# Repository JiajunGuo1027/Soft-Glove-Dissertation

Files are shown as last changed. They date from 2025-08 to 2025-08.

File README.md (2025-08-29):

# Design and Closed-Loop Control of a Cable-Driven Soft Robotic Glove for Post-Stroke Rehabilitation
This project aims to construct a soft glove-based passive rehabilitation training system to serve the finger rehabilitation process of patients with upper limb motor dysfunction after stroke.

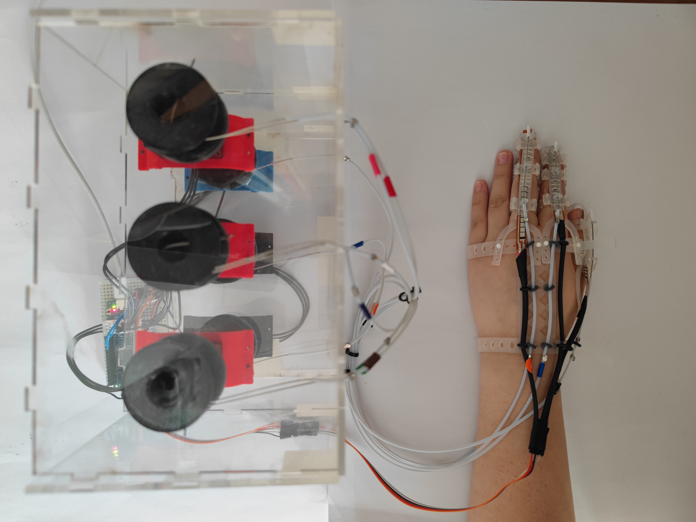
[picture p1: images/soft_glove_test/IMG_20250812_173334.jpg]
Description
 

## Overview
This repository contains the complete implementation of a **cable-driven soft exoskeleton glove** developed for passive rehabilitation of post-stroke patients.  
The system enables repeatable flexion–extension cycles of the thumb, index, and middle fingers using cable-driven actuation with integrated sensing and closed-loop control.  

Watch the video (https://youtu.be/nIMEAH1Ccxk)

**Key Features:**
- Modular glove design with silicone structures and 3D-printed connectors.  
- Six Dynamixel XL330-M288-T motors for tendon-driven flexion/extension.  
- Flex sensor–based multimodal modeling framework (L–θ, R–L, R–θ mappings).  
- Closed-loop controller with sensor-based angle estimation (camera-free).  
- Complete experimental pipeline including tensile testing, data acquisition, modeling, and evaluation.  

---

## Repository Structure
```
Soft_glove/
├─ code/ # Source code
│ ├─ script/anagle_detect/ # Video-based joint angle extraction
│ │ ├─ angle_detect_index.py
│ │ ├─ angle_detect_middle.py
│ │ └─ angle_detect_thumb.py
│ ├─ script/model/ # Modeling scripts (L–θ, R–L, R–θ)
│ │ ├─ model_L_theta.py
│ │ ├─ model_R_L.py
│ │ ├─ model_R_theta_compose_active.py
│ │ └─ model_R_theta_direct.py
│ └─ OpenRB150/ # Embedded control firmware
│   ├─ flex_extend_sensor_test/
│   │ └─ flex_extend_sensor_test.ino
│   └─ close_loop_control/
│     └─ close_loop_control.ino
│
├─ data/ # Raw experimental data
│ ├─ raw/ # Serial data logs
│ └─ video/ # Video recordings for joint angle extraction
│
├─ output/ # Processed results
│ ├─ index_angles/ # Aligned data for index finger
│ │ └─ aligned_data_index.csv
│ ├─ middle_angles/ # Aligned data for middle finger
│ │ └─ aligned_data_middle.csv
│ ├─ thumb_angles/ # Aligned data for thumb
│ │ └─ aligned_data_thumb.csv
│ └─ control_results/ # Closed-loop control logs and evaluation plots
│
├─ models/ # Trained models (JSON/CSV/plots)
│ ├─ index/
│ │ ├─ L_theta/ L_theta_model.json, L_theta_summary_index.csv
│ │ ├─ R_L/ R_L_model.json, R_L_summary_index.csv
│ │ ├─ R_theta_direct/ R_theta_direct_model_index.json
│ │ └─ R_theta_compose_active/ (composed model + active session data)
│ ├─ middle/ # Similar structure, mainly R–L models
│ └─ thumb/ # Same as index
│
├─ images/ # Figures and plots for reports/papers
│ ├─ article/ # Final paper figures
│ ├─ design_sketch/ # Glove design illustrations
│ └─ soft_glove_test/ # Project photos
│
├─ SOLIDWORKS 2024/ # CAD models
│ ├─ Glove_final_design/ # Final glove design
│ ├─ 3D_Print_connector/ # Connector models
│ └─ other .SLDPRT files # Palm and finger modules
│
├─ tensile/ # Tensile testing data and results
└─ requirements.txt # Python dependencies
```

---

## Core Files

- **Final aligned data:**  
  - `output/index_angles/aligned_data_index.csv`  
  - `output/middle_angles/aligned_data_middle.csv`  
  - `output/thumb_angles/aligned_data_thumb.csv`  

- **Key trained models:**  
  - `models/index/L_theta/L_theta_model.json`  
  - `models/index/R_L/R_L_model.json`  
  - `models/index/R_theta_compose_active/R_theta_composed_model_ACTIVE.json`  

- **Control firmware:**  
  - `code/OpenRB150/close_loop_control/close_loop_control.ino`

---

## How to Use

1. **Preprocess video & sensor data**  
   Run scripts in `code/script/anagle_detect/` to extract joint angles from marker-based video.  

2. **Train models (L–θ, R–L, R–θ)**  
   Use the scripts in `code/script/model/` to fit regression models.  

3. **Upload firmware**  
   Flash `closeloop_control.ino` to the OpenRB-150 board.  

4. **Run closed-loop experiments**  
   Collect results in `output/control_results/` and visualize using provided Python scripts.  

---

## Notes
- The repository also contains **debug files, early tests, and discarded attempts** for completeness and reproducibility.  
- Final analysis and plots for the dissertation were generated from the files highlighted in **Core Files**.  

---

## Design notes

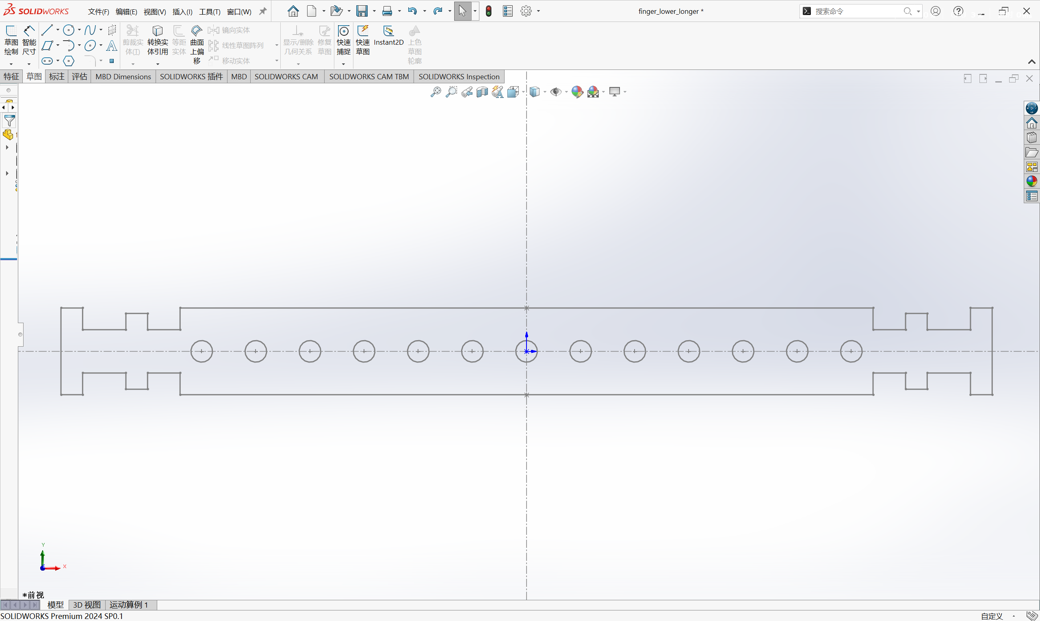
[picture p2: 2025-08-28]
images/design_sketch/finger_lower_longer.png

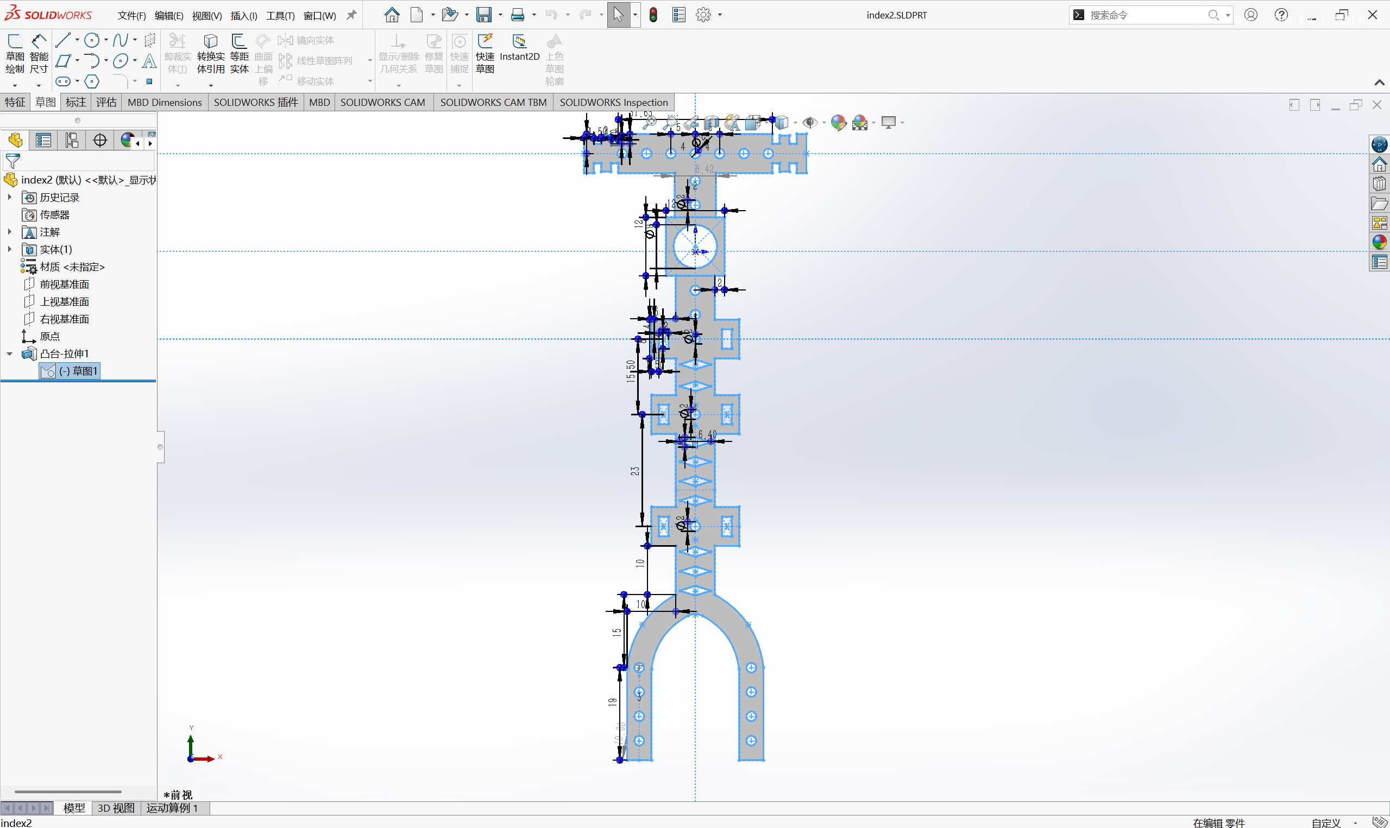
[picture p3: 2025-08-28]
images/design_sketch/index_upper_sketch.png

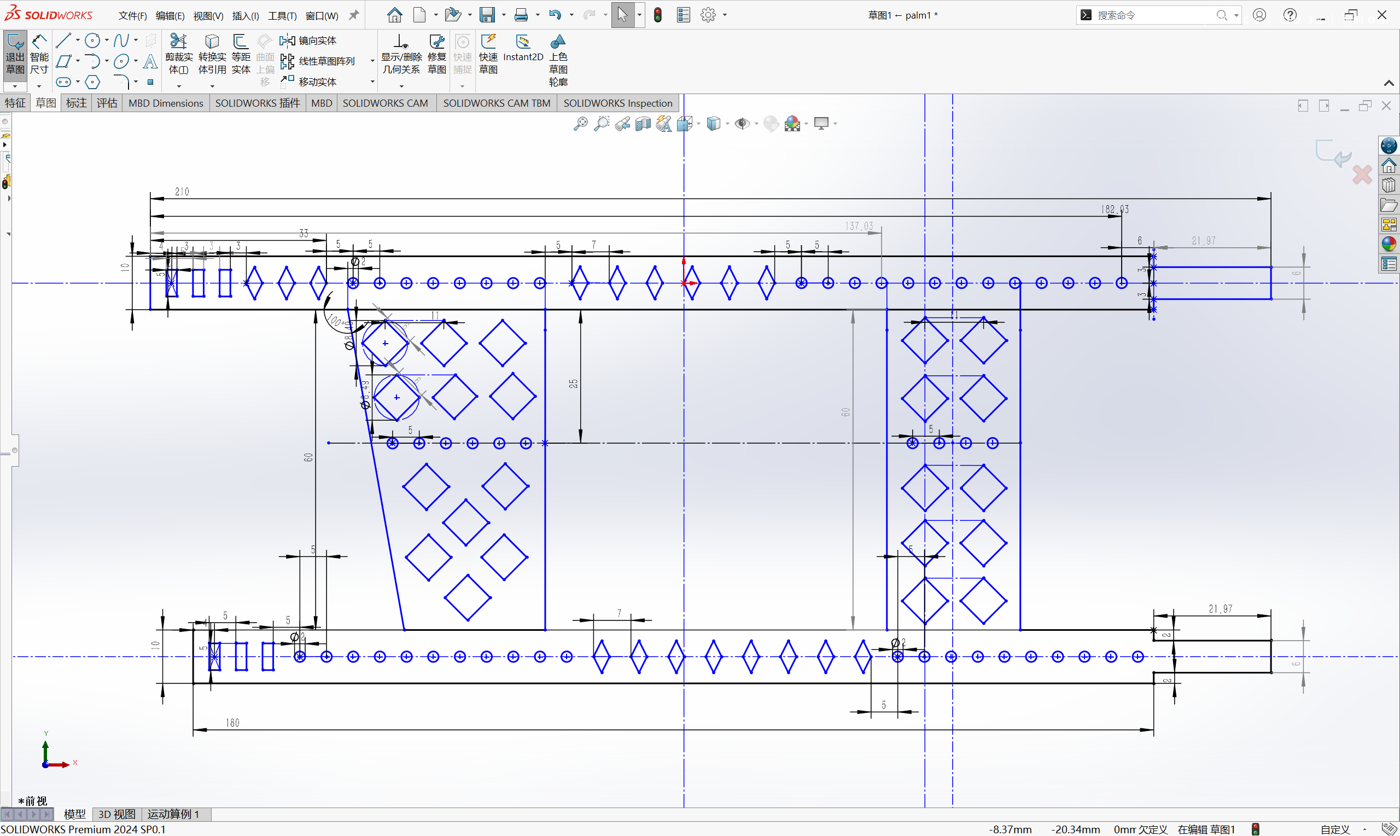
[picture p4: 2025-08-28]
images/design_sketch/palm_sketch.png

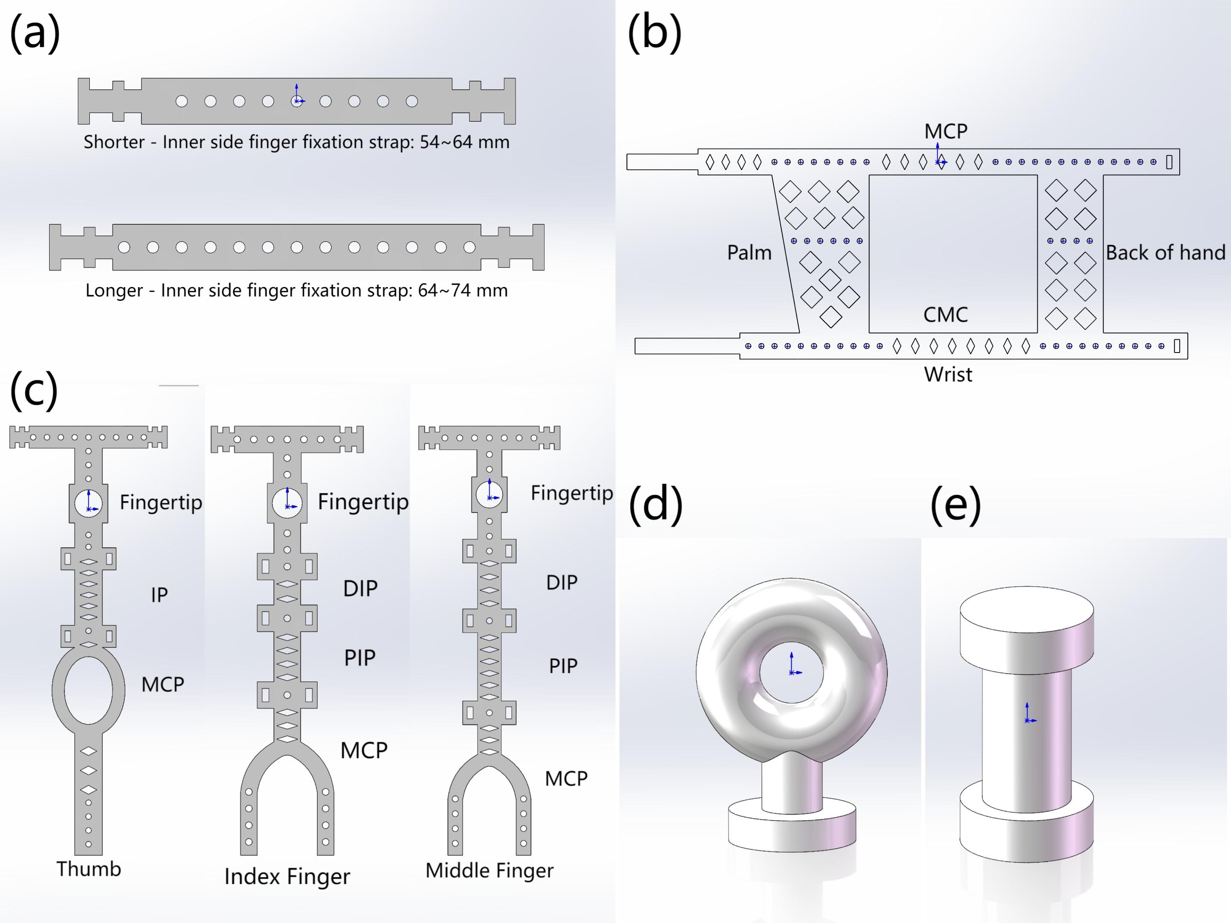
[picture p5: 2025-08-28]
images/article/design.jpg

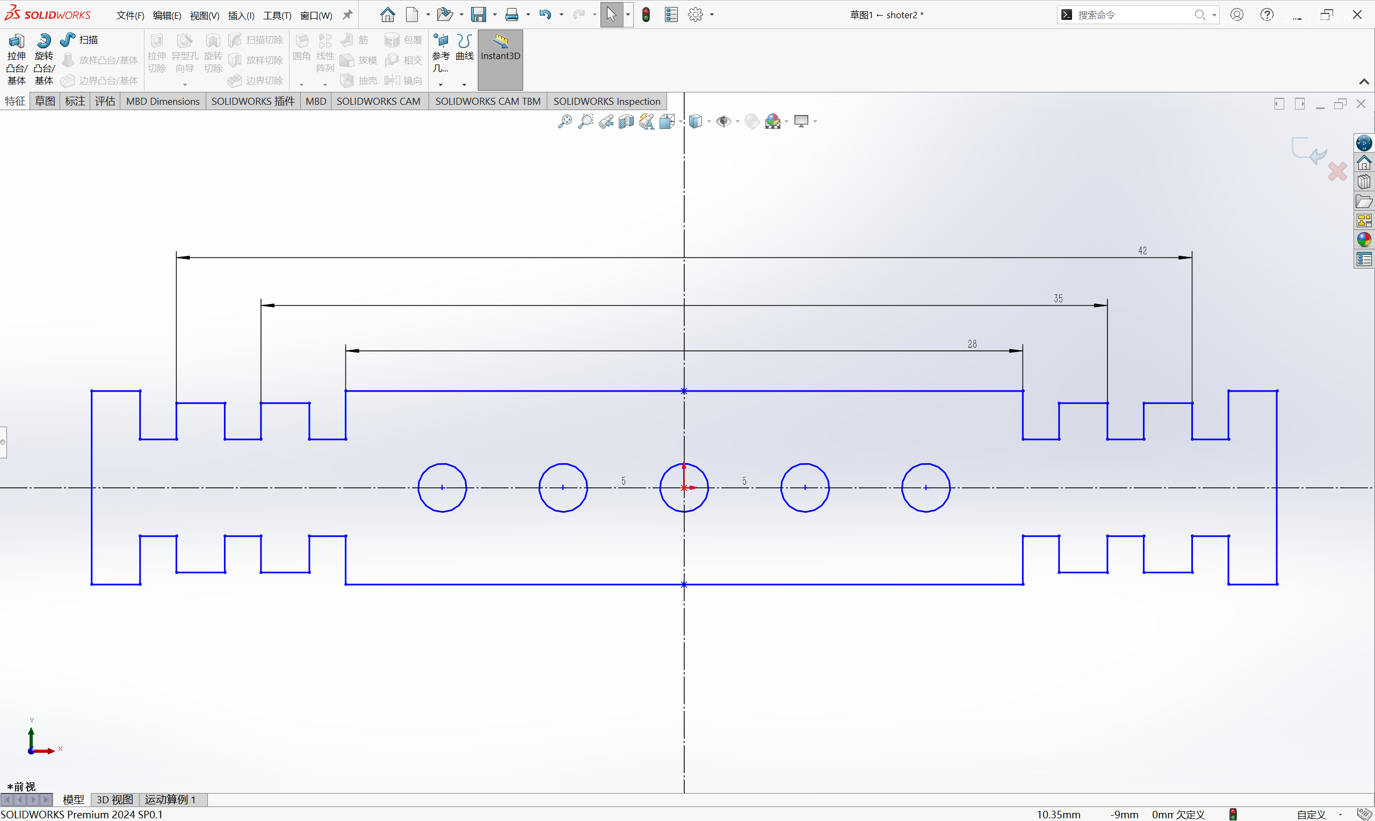
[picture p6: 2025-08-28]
images/design_sketch/shoter2.png

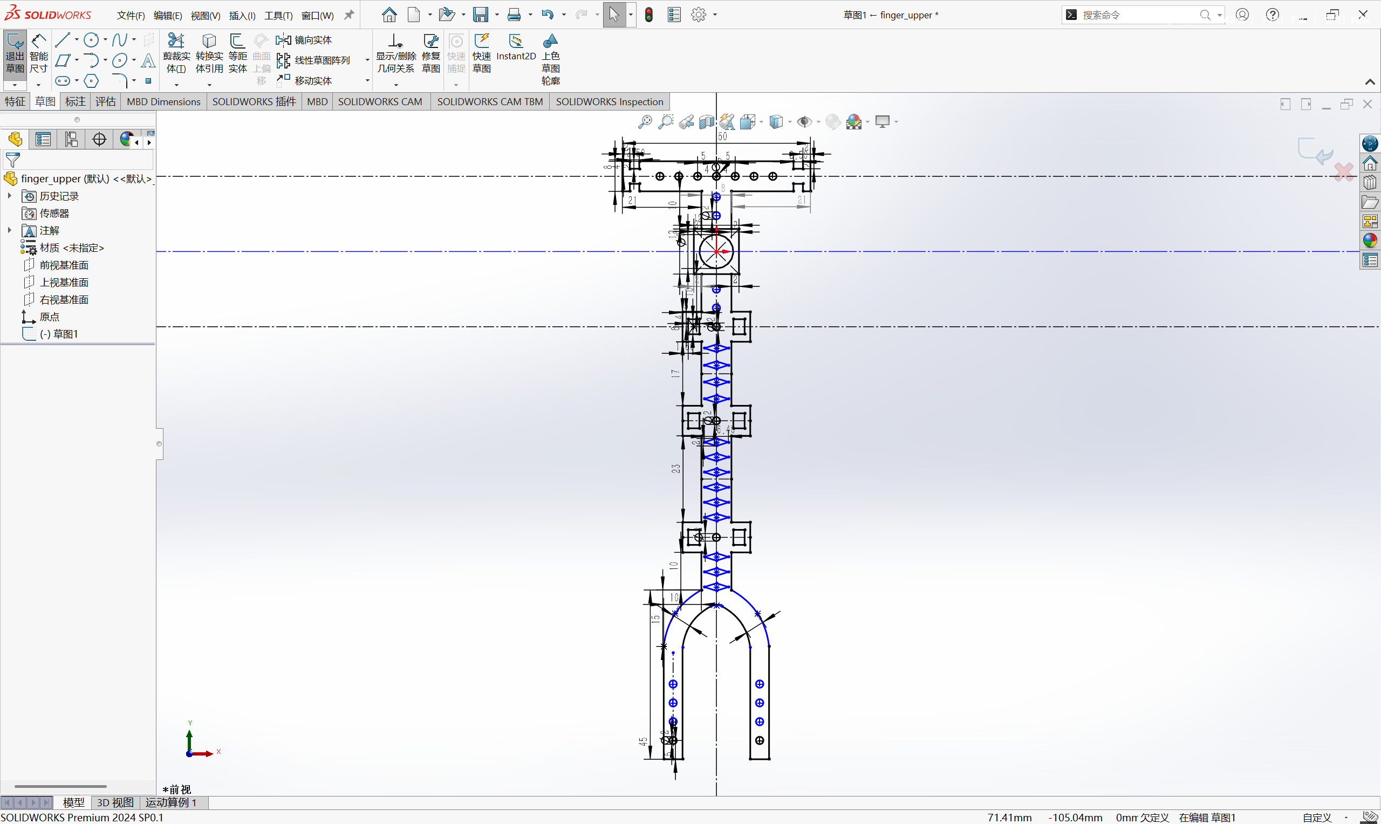
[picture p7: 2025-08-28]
images/design_sketch/finger_upper_sketch.png

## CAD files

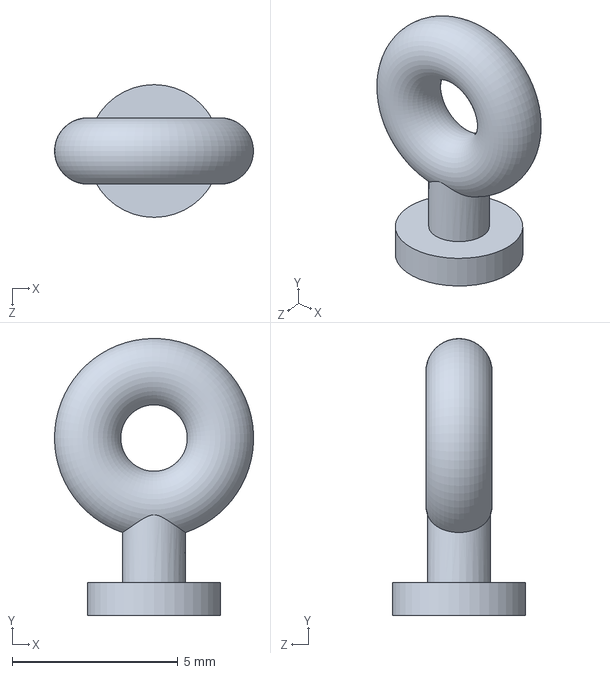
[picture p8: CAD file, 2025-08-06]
SOLIDWORKS 2024/3D_Print/30_cable2mm.SLDPRT
6.00 x 8.34 x 4.00 mm

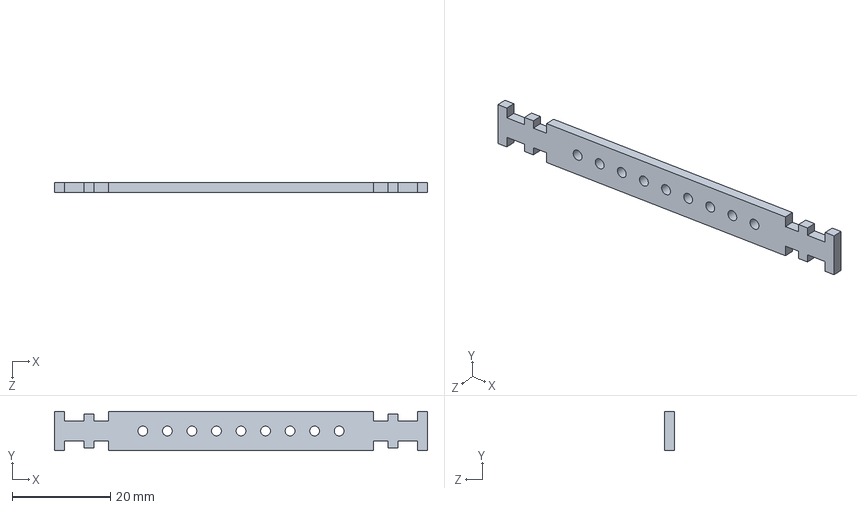
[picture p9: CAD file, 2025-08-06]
SOLIDWORKS 2024/finger_lower_shoter_3D.SLDPRT
76.0 x 8.00 x 2.00 mm

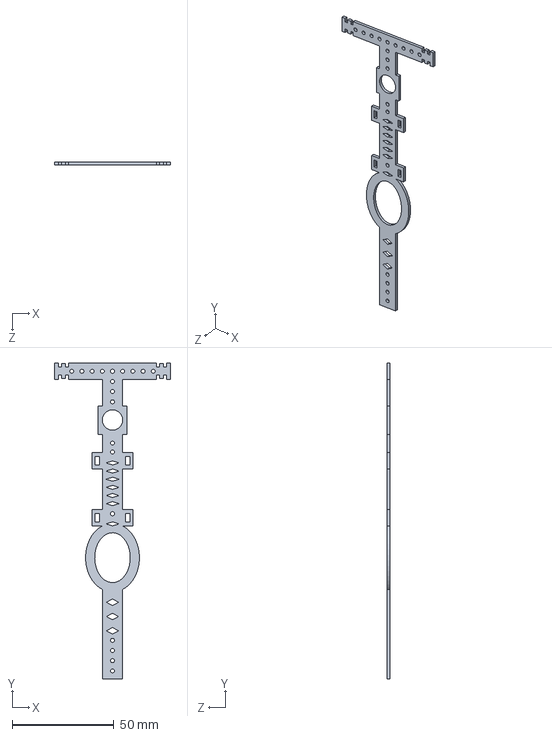
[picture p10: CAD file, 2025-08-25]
SOLIDWORKS 2024/Glove_final_design/thumb3.SLDPRT
57.0 x 155.1 x 1.50 mm

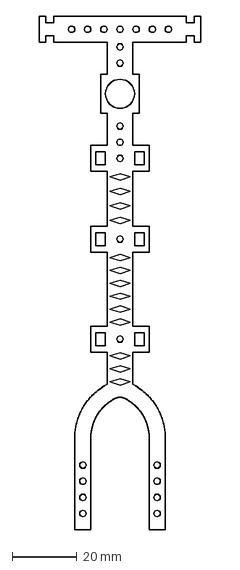
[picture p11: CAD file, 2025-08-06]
SOLIDWORKS 2024/LaserCut1/finger_upper_3D.DXF
50.0 x 159.0 mm

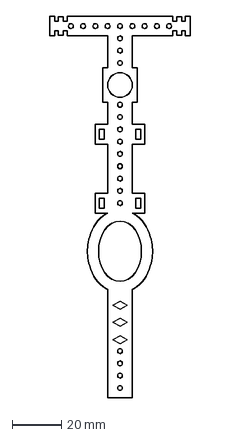
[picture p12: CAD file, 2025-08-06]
SOLIDWORKS 2024/LaserCut2/1_thumb2.DXF
57.0 x 155.1 mm

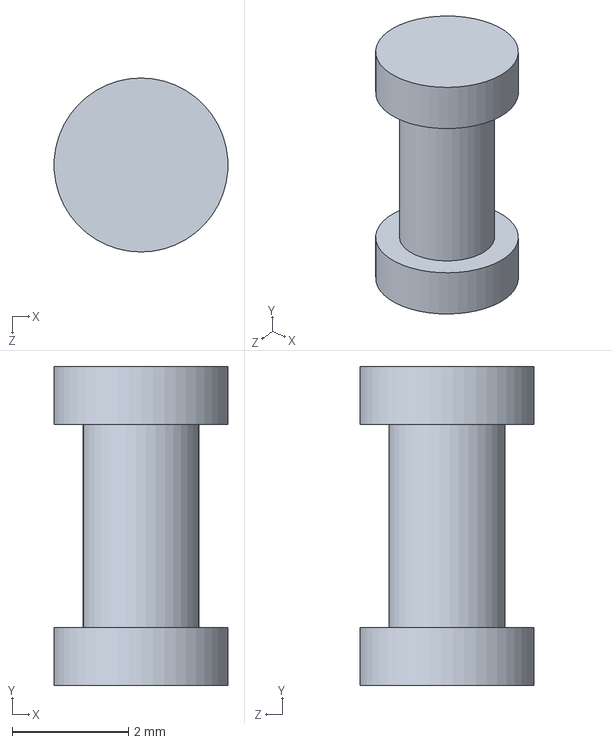
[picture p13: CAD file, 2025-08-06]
SOLIDWORKS 2024/3D_Print/10_connector1.SLDPRT
2.99 x 5.50 x 3.00 mm

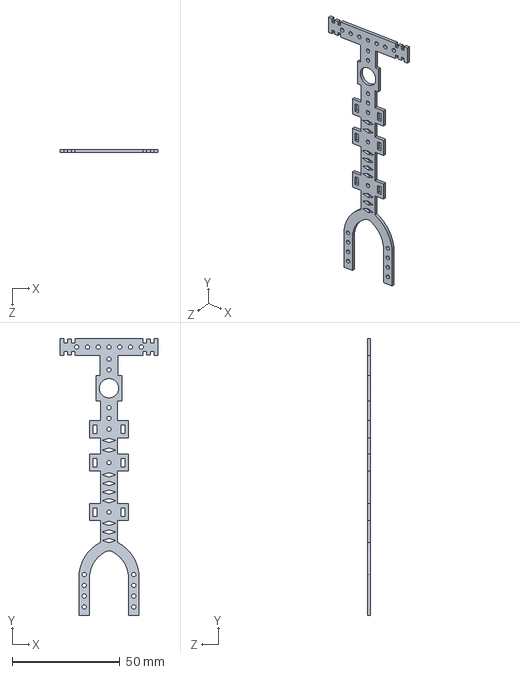
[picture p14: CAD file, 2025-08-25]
SOLIDWORKS 2024/Glove_final_design/index2.SLDPRT
45.6 x 128.6 x 1.50 mm

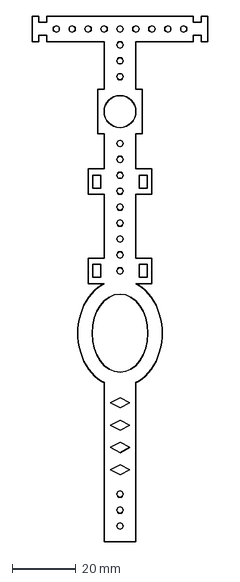
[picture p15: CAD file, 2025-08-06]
SOLIDWORKS 2024/LaserCut1/thumb_upper_3D.DXF
55.0 x 165.1 mm

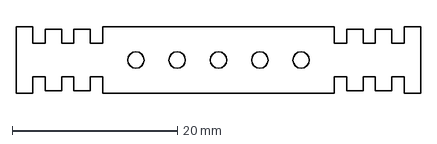
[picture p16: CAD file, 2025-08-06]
SOLIDWORKS 2024/LaserCut2/3_shoter2.DXF
49.0 x 8.00 mm

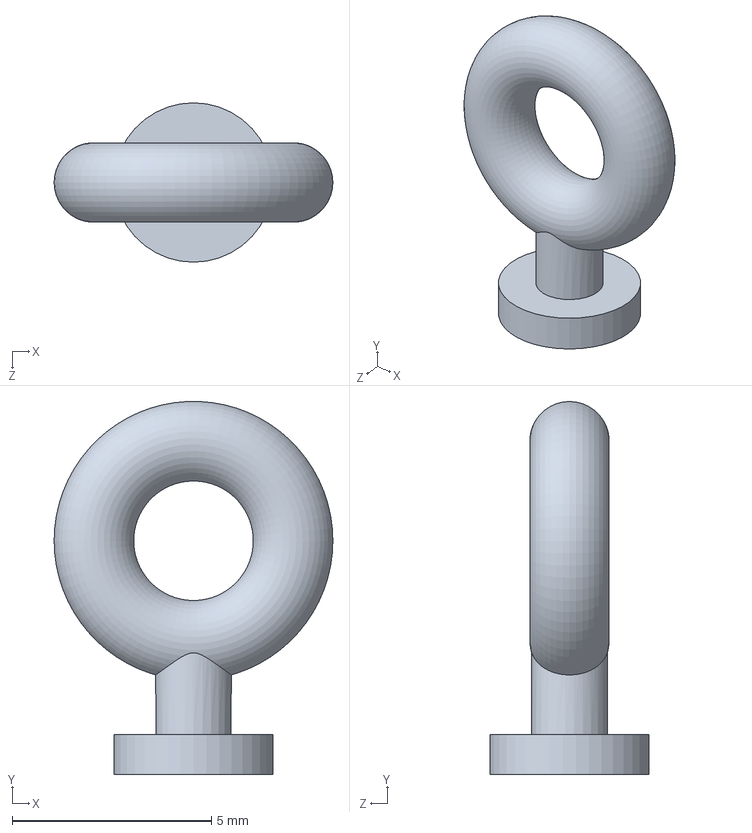
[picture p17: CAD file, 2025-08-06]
SOLIDWORKS 2024/3D_Print/30_cable3mm.SLDPRT
7.00 x 9.37 x 4.00 mm

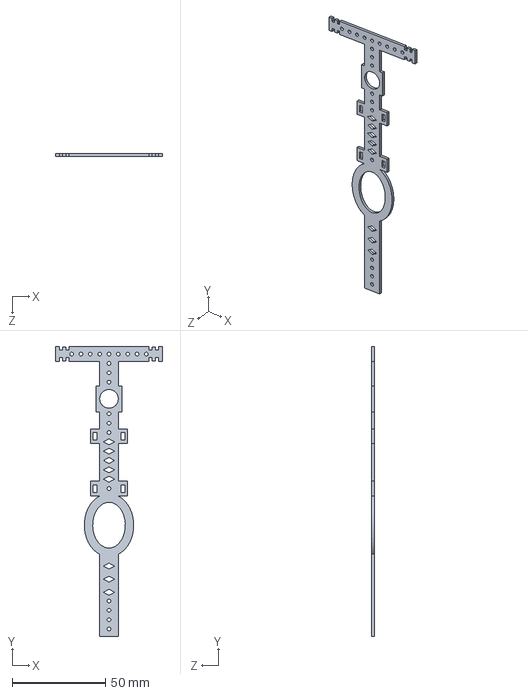
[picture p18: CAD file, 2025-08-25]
SOLIDWORKS 2024/Glove_final_design/thumb2.SLDPRT
57.0 x 155.1 x 1.50 mm

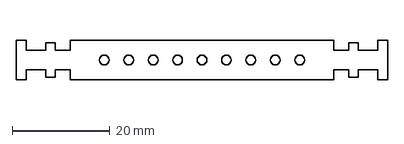
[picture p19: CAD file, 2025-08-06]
SOLIDWORKS 2024/LaserCut1/finger_lower_shoter_3D.DXF
76.0 x 8.00 mm

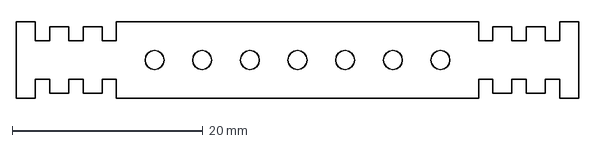
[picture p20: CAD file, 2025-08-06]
SOLIDWORKS 2024/LaserCut2/3_longer2.DXF
59.0 x 8.00 mm

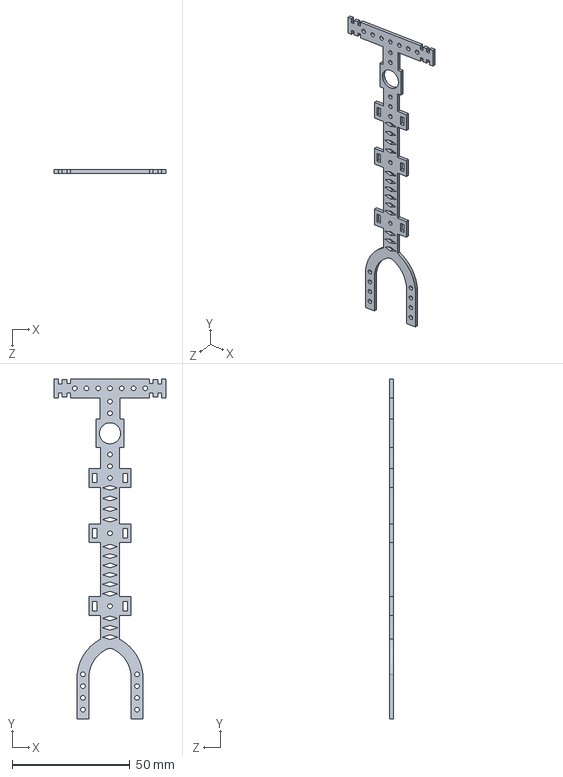
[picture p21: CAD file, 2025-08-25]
SOLIDWORKS 2024/Glove_final_design/middle2.SLDPRT
47.6 x 144.6 x 1.50 mm

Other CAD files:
SOLIDWORKS 2024/finger_lower_longer.SLDPRT
SOLIDWORKS 2024/finger_under1.SLDPRT
SOLIDWORKS 2024/finger_lower_2D.SLDPRT
SOLIDWORKS 2024/LaserCut1/finger_lower_longer _3D.DXF
SOLIDWORKS 2024/Glove_final_design/longer2.SLDPRT
SOLIDWORKS 2024/Glove_final_design/palm2.SLDPRT
SOLIDWORKS 2024/Glove_final_design/shoter2.SLDPRT
SOLIDWORKS 2024/LaserCut1/palm1_3D.DXF
SOLIDWORKS 2024/LaserCut2/1_index2.DXF
SOLIDWORKS 2024/LaserCut2/1_middle2.DXF
SOLIDWORKS 2024/LaserCut2/1_palm2.DXF
SOLIDWORKS 2024/finger_lower_longer _3D.SLDPRT
SOLIDWORKS 2024/finger_lower_shoter.SLDPRT
SOLIDWORKS 2024/finger_upper.SLDPRT
SOLIDWORKS 2024/finger_upper_3D.SLDPRT
SOLIDWORKS 2024/palm1.SLDPRT
SOLIDWORKS 2024/palm1_3D.SLDPRT
SOLIDWORKS 2024/thumb1.SLDPRT
SOLIDWORKS 2024/thumb_upper.SLDPRT
SOLIDWORKS 2024/thumb_upper_3D.SLDPRT
SOLIDWORKS 2024/train.SLDPRT

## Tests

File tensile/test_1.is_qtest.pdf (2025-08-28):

Sample text inputs: Sample text input | thumb0

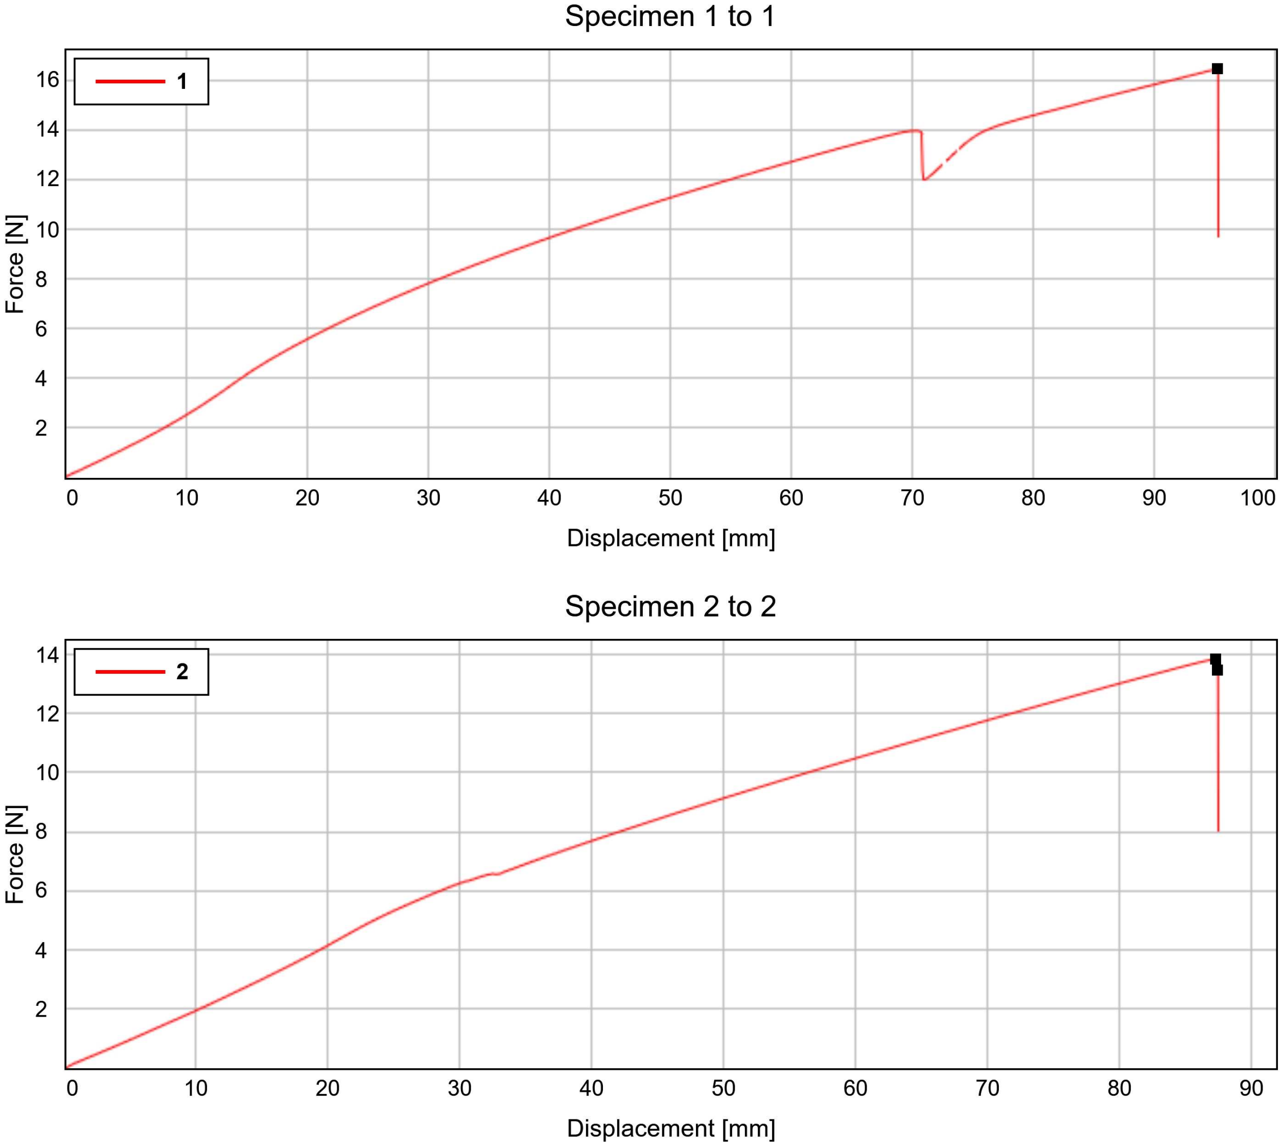
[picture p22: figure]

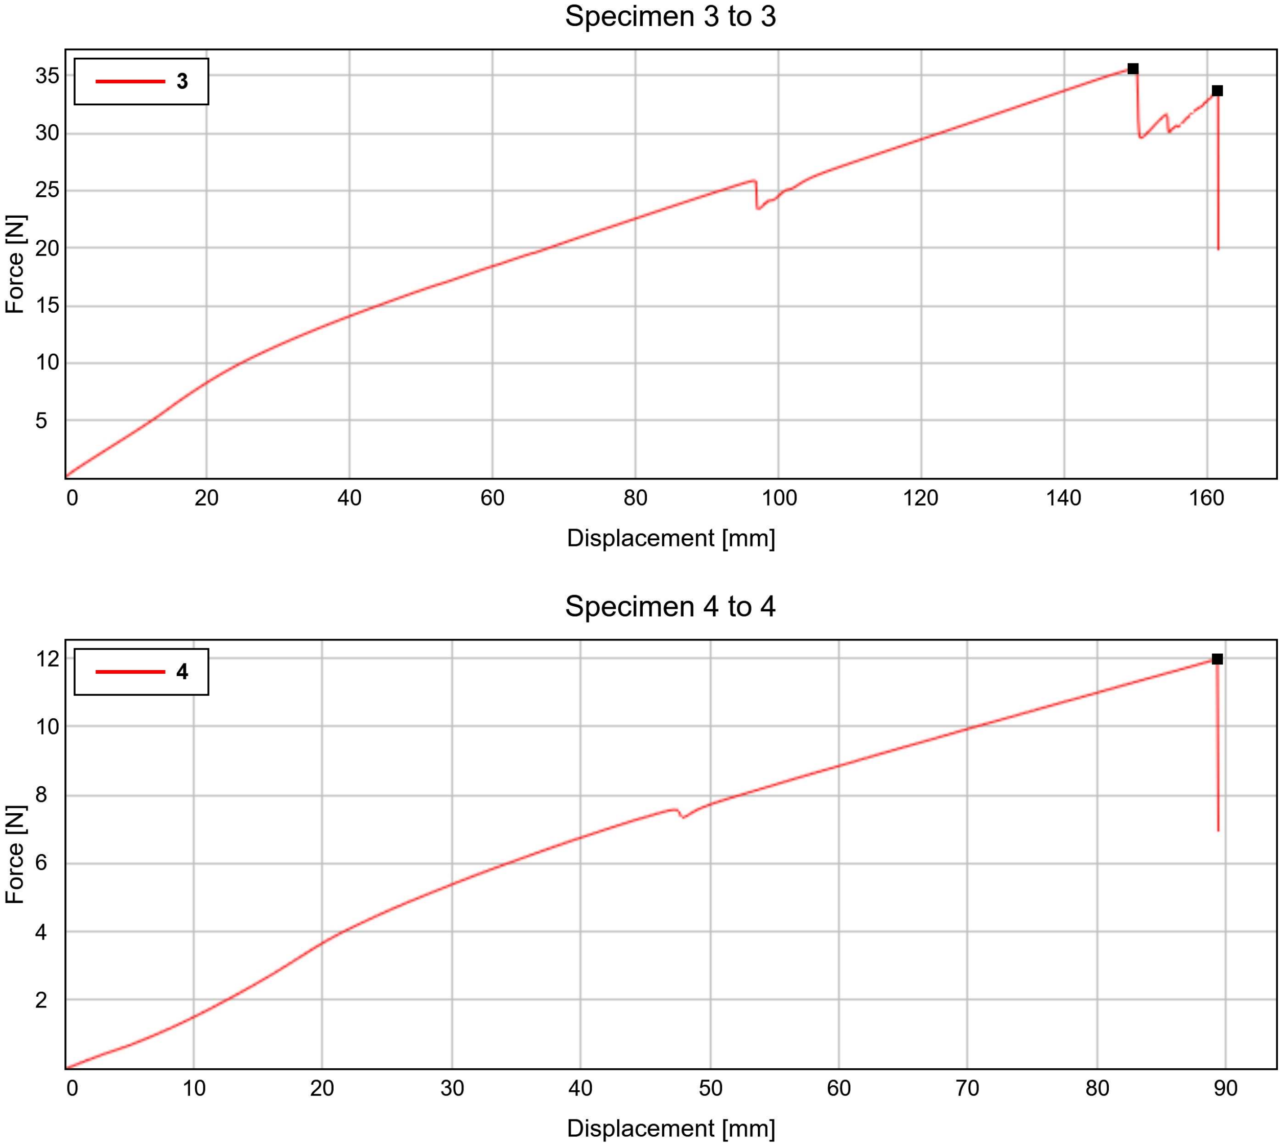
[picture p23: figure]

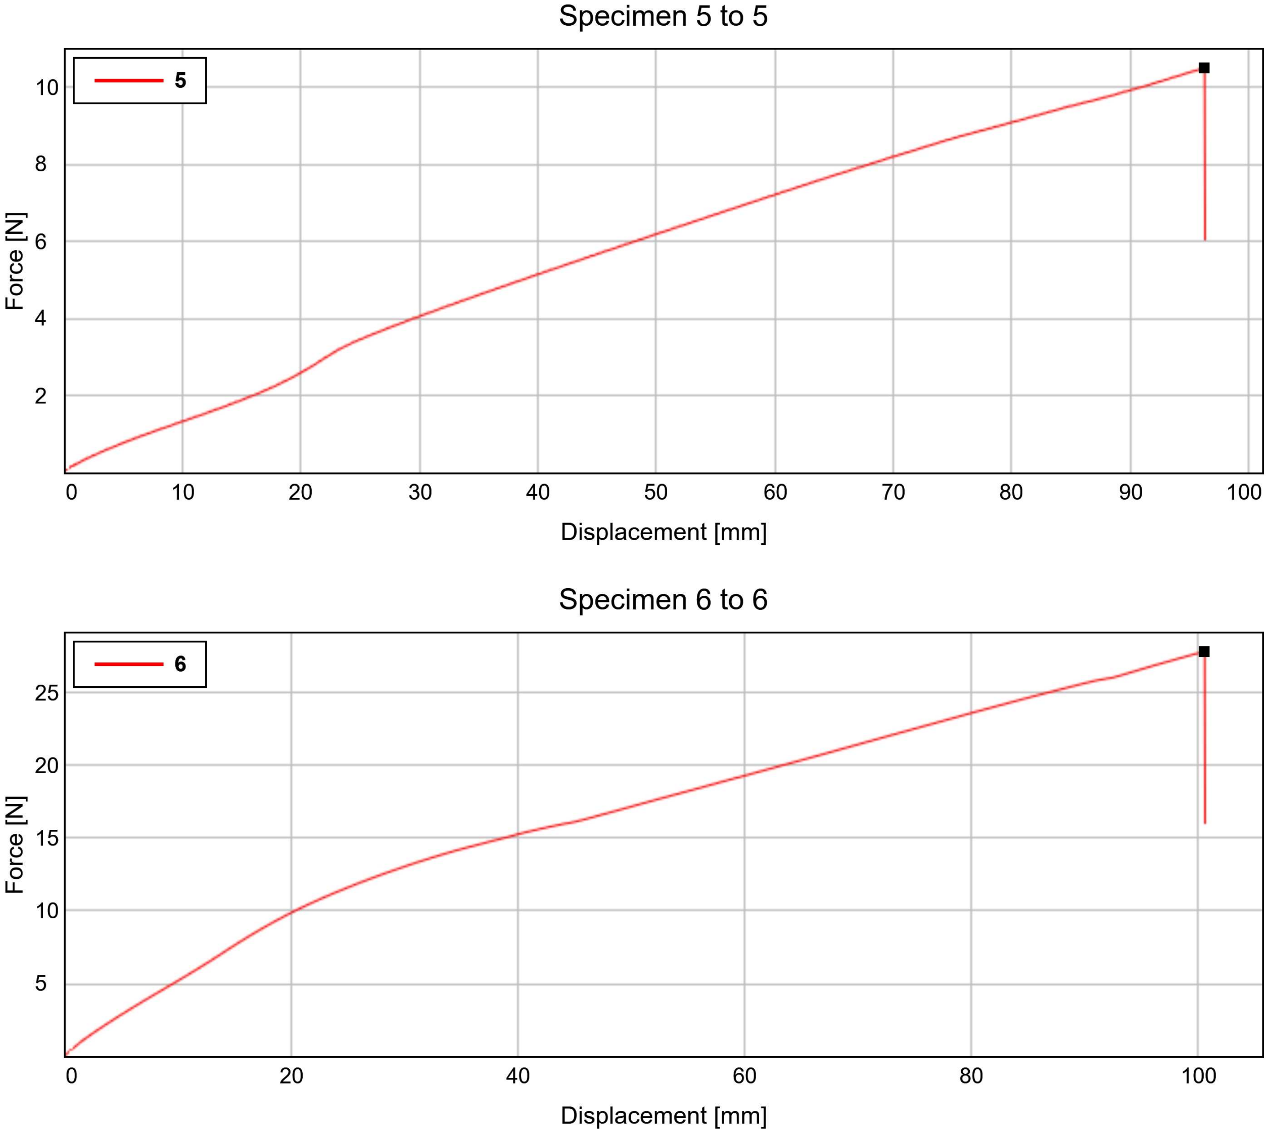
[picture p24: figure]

| Maximum Force [N] | Displacement at Maximum Force [mm] | Maximum Displacement [mm]
3 | 35.58 | 149.73 | 161.61
6 | 27.83 | 100.55 | 100.59
1 | 16.44 | 95.22 | 95.33
2 | 13.84 | 87.23 | 87.51
4 | 11.97 | 89.31 | 89.39
5 | 10.49 | 96.30 | 96.34

Force at Break
(Standard)
[N]

Specimen text input Specimen note

| Force at Break (Standard) [N] | Specimen text input | Specimen note
3 | 33.64
6 | 27.83
1 | 16.44
2 | 13.45
4 | 11.97
5 | 10.49

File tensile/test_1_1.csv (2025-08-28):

Results Table 1
 | Maximum Force | Displacement at Maximum Force | Maximum Displacement | Force at Break (Standard) | Specimen text input | Specimen note
 | (N) | (mm) | (mm) | (N)
1 | 16.44 | 95.22 | 95.33 | 16.44
2 | 13.84 | 87.23 | 87.51 | 13.45
3 | 35.58 | 149.73 | 161.61 | 33.64
4 | 11.97 | 89.31 | 89.39 | 11.97
5 | 10.49 | 96.30 | 96.34 | 10.49
6 | 27.83 | 100.55 | 100.59 | 27.83
Results Table 2

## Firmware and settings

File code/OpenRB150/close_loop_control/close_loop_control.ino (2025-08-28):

/* OpenRB-150 + Dynamixel XL330 + Flex sensors
 * - Index/Thumb: θ-domain closed-loop (R->L->θ feedback, θ_target->L_target feedforward)
 * - Middle: L-domain closed-loop (R->L feedback)
 * - Phase beeps on transitions, 20 ms loop, CSV streaming log
 *
 */

#include <Dynamixel2Arduino.h>

// ---------- Board / Ports ----------
#define USB_BAUD     115200
#define DXL_BAUD     1000000

#define DXL_PORT     Serial3
#define DXL_DIR_PIN  -1  

// ---------- Pins ----------
#define BUZZER_PIN   10
#define PIN_A0       A0   // Thumb
#define PIN_A1       A1   // Index
#define PIN_A2       A2   // Middle

// ---------- Timing ----------
#define LOOP_DT_MS   20UL
#define BEEP_MS      120

// ---------- Dynamixel ----------
Dynamixel2Arduino dxl(DXL_PORT, DXL_DIR_PIN);
const float TICKS_PER_RAD = 4096.0f / (2.0f * 3.1415926535f);
const uint8_t ID_T_FLEX = 1, ID_I_FLEX = 2, ID_M_FLEX = 3;
const uint8_t ID_T_EXT  = 4, ID_I_EXT  = 5, ID_M_EXT  = 6;

int8_t SIGN_T_FLEX = +1, SIGN_I_FLEX = +1, SIGN_M_FLEX = +1;
int8_t SIGN_T_EXT  = -1, SIGN_I_EXT  = -1, SIGN_M_EXT  = -1;

// Home offsets (ticks) captured at start
int32_t HOME_T_FLEX=0, HOME_I_FLEX=0, HOME_M_FLEX=0;
int32_t HOME_T_EXT =0, HOME_I_EXT =0, HOME_M_EXT =0;

// ---------- Model structs ----------
struct RLPhase {
  float a, b, c;       // L = a*z^2 + b*z + c  (cm);  z = (R - lo)/(hi - lo)
  float lo, hi;        // sensor normalization bounds
  float Lmin, Lmax;    // safe L range (cm)
};

struct LThetaPhase {
  float a, b, c;       // theta = a*L^2 + b*L + c  (deg)
  float Tmin, Tmax;    // safe theta range (deg)
};

struct FingerModel {
  // R->L per phase
  RLPhase flex_rl, ext_rl;
  // L->theta per phase (index/thumb); for middle no need but keep for proxy
  LThetaPhase flex_lt, ext_lt;
  // Affine theta correction (optional, default 1,0)
  float aff_a, aff_b;
  // Spool radius (cm)
  float spool_r_cm;
};


struct MotorTargets { int32_t flex_ticks; int32_t ext_ticks; };


// Global models for three fingers
FingerModel F_IDX, F_THU, F_MID;

// ---------- Control / State ----------
enum Phase { PH_FLEX=0, PH_EXT=1 };
struct FingerState {
  Phase phase;
  float t_in_phase;       // s
  float period;           // s, full cycle = 2*period for triangular profile
  float theta_lo, theta_hi;  // deg for index/thumb
  float L_lo_cm, L_hi_cm;    // cm for middle
  // PID (θ-domain for index/thumb; L-domain for middle)
  float Kp, Ki, Kd;
  float integ;
  float prev_err;
};

FingerState S_IDX, S_THU, S_MID;

// trajectory type: 0=triangle, 1=sine, 2=step
uint8_t TRAJ_TYPE = 0;
uint16_t CYCLES_TO_RUN = 6;
uint16_t cycles_done = 0;

// ---------- Helpers ----------
float clampf(float v, float lo, float hi){ if(v<lo) return lo; if(v>hi) return hi; return v; }
float radiansf(float deg){ return deg*3.1415926535f/180.0f; }
float degreesf(float rad){ return rad*180.0f/3.1415926535f; }

float z_norm(float R, float lo, float hi){
  float den = (hi>lo)? (hi-lo) : 1e-9f;
  return (R - lo)/den;
}

float sensor_to_L(const RLPhase& ph, float Rraw){
  float z = z_norm(Rraw, ph.lo, ph.hi);
  float L = ph.a*z*z + ph.b*z + ph.c;
  return clampf(L, ph.Lmin, ph.Lmax);
}

float L_to_theta(const LThetaPhase& ph, float L){
  float th = ph.a*L*L + ph.b*L + ph.c;
  return clampf(th, ph.Tmin, ph.Tmax);
}

// Invert theta = a*L^2 + b*L + c  ->  L 
bool theta_to_L(const LThetaPhase& ph, float theta, float lastL, float* Lout){
  float A = ph.a, B = ph.b, C = ph.c - theta;
  float disc = B*B - 4*A*C;
  if(disc < 0) return false;
  float sqrtD = sqrtf(disc);
  float L1 = (-B + sqrtD)/(2*A);
  float L2 = (-B - sqrtD)/(2*A);
  // pick root closest to lastL
  float Lpick = (fabsf(L1 - lastL) < fabsf(L2 - lastL)) ? L1 : L2;
  if(Lpick < -1000 || Lpick > 1000) return false;
  *Lout = clampf(Lpick, ph.Tmin, ph.Tmax); 
  return true;
}

// safer clamp for L using model ranges
float clampL(float L, const RLPhase& rl){ return clampf(L, rl.Lmin, rl.Lmax); }

// θ estimate from sensor: θ = aff( L(R) -> θ(L) )
float theta_from_R(const FingerModel& M, Phase ph, float Rraw){
  const RLPhase& rlp = (ph==PH_FLEX)? M.flex_rl : M.ext_rl;
  const LThetaPhase& ltp = (ph==PH_FLEX)? M.flex_lt : M.ext_lt;
  float L = sensor_to_L(rlp, Rraw);
  float th = L_to_theta(ltp, L);
  return M.aff_a*th + M.aff_b;
}

// move DXL to absolute ticks with simple saturation of goal velocity via Profile params
void set_goal_ticks(uint8_t id, int32_t ticks){
  dxl.setGoalPosition(id, (float)ticks);
}

int32_t read_present_ticks(uint8_t id){
  return (int32_t)dxl.getPresentPosition(id);
}

// Simple beep
void beep(uint16_t dur_ms=BEEP_MS){
  pinMode(BUZZER_PIN, OUTPUT);
  digitalWrite(BUZZER_PIN, HIGH); delay(dur_ms);
  digitalWrite(BUZZER_PIN, LOW);
}



String sline;

FingerModel* selFinger(const String& tag){
  if(tag=="IDX") return &F_IDX;
  if(tag=="THU") return &F_THU;
  if(tag=="MID") return &F_MID;
  return nullptr;
}

void applyRL(FingerModel* F, bool isFlex, float a,float b,float c,float lo,float hi,float Lmin,float Lmax){
  RLPhase& ph = isFlex? F->flex_rl : F->ext_rl;
  ph.a=a; ph.b=b; ph.c=c; ph.lo=lo; ph.hi=hi; ph.Lmin=Lmin; ph.Lmax=Lmax;
}
void applyLTH(FingerModel* F, bool isFlex, float a,float b,float c,float Tmin,float Tmax){
  LThetaPhase& ph = isFlex? F->flex_lt : F->ext_lt;
  ph.a=a; ph.b=b; ph.c=c; ph.Tmin=Tmin; ph.Tmax=Tmax;
}

void process_line(const String& line){

  const int MAXTOK=16;
  String tok[MAXTOK]; int n=0;
  int start=0;
  for(int i=0;i<line.length() && n<MAXTOK;i++){
    if(line[i]==','){ tok[n++] = line.substring(start,i); start=i+1; }
    else if(i==line.length()-1){ tok[n++] = line.substring(start,i+1); }
  }
  if(n==0) return;
  if(tok[0]!="CFG") return;

  if(n>=3 && tok[2]=="RUN"){
    CYCLES_TO_RUN = (uint16_t)tok[3].toInt();
    cycles_done = 0;
    // beep twice to mark start
    beep(80); delay(80); beep(80);
    return;
  }

  if(n<4) return;
  FingerModel* F = selFinger(tok[1]);
  String type = tok[3];

  if(type=="RLQ" && n>=12){
    bool isFlex = (tok[2]=="FLEX");
    applyRL(F,isFlex, tok[4].toFloat(),tok[5].toFloat(),tok[6].toFloat(),
                 tok[7].toFloat(),tok[8].toFloat(),tok[9].toFloat(),tok[10].toFloat());
  } else if(type=="LTHQ" && n>=11){
    bool isFlex = (tok[2]=="FLEX");
    applyLTH(F,isFlex, tok[4].toFloat(),tok[5].toFloat(),tok[6].toFloat(),
                    tok[7].toFloat(),tok[8].toFloat());
  } else if(type=="AFF" && n>=6){
    F->aff_a = tok[4].toFloat(); F->aff_b = tok[5].toFloat();
  } else if(type=="SPOOL" && n>=5){
    F->spool_r_cm = tok[4].toFloat();
  } else if(type=="PID" && n>=7){
    FingerState* S = (tok[1]=="IDX")? &S_IDX : (tok[1]=="THU")? &S_THU : &S_MID;
    S->Kp = tok[4].toFloat(); S->Ki = tok[5].toFloat(); S->Kd = tok[6].toFloat();
  } else if(type=="TRAJ" && n>=9){
    FingerState* S = (tok[1]=="IDX")? &S_IDX : &S_THU;
    TRAJ_TYPE = (uint8_t)tok[4].toInt();
    S->period   = tok[5].toFloat();
    S->theta_lo = tok[6].toFloat();
    S->theta_hi = tok[7].toFloat();
    S->t_in_phase = 0; S->phase = PH_FLEX; S->integ=0; S->prev_err=0;
  } else if(type=="TRAJ_L" && n>=9){
    FingerState* S = &S_MID;
    TRAJ_TYPE = (uint8_t)tok[4].toInt();
    S->period   = tok[5].toFloat();
    S->L_lo_cm  = tok[6].toFloat();
    S->L_hi_cm  = tok[7].toFloat();
    S->t_in_phase = 0; S->phase = PH_FLEX; S->integ=0; S->prev_err=0;
  } else if(type=="SIGN" && n>=7){
    int8_t fs = (int8_t)tok[4].toInt();
    int8_t es = (int8_t)tok[5].toInt();
    if(tok[1]=="IDX"){ SIGN_I_FLEX=fs; SIGN_I_EXT=es; }
    else if(tok[1]=="THU"){ SIGN_T_FLEX=fs; SIGN_T_EXT=es; }
    else { SIGN_M_FLEX=fs; SIGN_M_EXT=es; }
  }
}

// ---------- Setup ----------
void setup(){
  pinMode(BUZZER_PIN, OUTPUT);
  digitalWrite(BUZZER_PIN, LOW);
  Serial.begin(USB_BAUD);

  dxl.begin(DXL_BAUD);
  dxl.setPortProtocolVersion(2.0);

  uint8_t ids[6] = {ID_T_FLEX, ID_I_FLEX, ID_M_FLEX, ID_T_EXT, ID_I_EXT, ID_M_EXT};

  for (int i = 0; i < 6; i++) {
    uint8_t cur = ids[i];
    dxl.torqueOff(cur);
    dxl.setOperatingMode(cur, OP_POSITION);
    dxl.writeControlTableItem(ControlTableItem::PROFILE_VELOCITY,     cur, 90);
    dxl.writeControlTableItem(ControlTableItem::PROFILE_ACCELERATION, cur,  20);
    dxl.torqueOn(cur);
  }

  // capture homes
  HOME_T_FLEX = read_present_ticks(ID_T_FLEX);
  HOME_I_FLEX = read_present_ticks(ID_I_FLEX);
  HOME_M_FLEX = read_present_ticks(ID_M_FLEX);
  HOME_T_EXT  = read_present_ticks(ID_T_EXT);
  HOME_I_EXT  = read_present_ticks(ID_I_EXT);
  HOME_M_EXT  = read_present_ticks(ID_M_EXT);

  // defaults
  F_IDX.aff_a=1; F_IDX.aff_b=0; F_THU.aff_a=1; F_THU.aff_b=0; F_MID.aff_a=1; F_MID.aff_b=0;
  F_IDX.spool_r_cm=1.0f; F_THU.spool_r_cm=1.0f; F_MID.spool_r_cm=1.0f;
  S_IDX.period=1.5f; S_THU.period=1.5f; S_MID.period=1.5f;
  S_IDX.theta_lo=0; S_IDX.theta_hi=45;
  S_THU.theta_lo=0; S_THU.theta_hi=40;
  S_MID.L_lo_cm=0;  S_MID.L_hi_cm=1.0f;
  S_IDX.Kp=0.8f; S_IDX.Ki=0.0f; S_IDX.Kd=0.02f;
  S_THU.Kp=0.8f; S_THU.Ki=0.0f; S_THU.Kd=0.02f;
  S_MID.Kp=0.6f; S_MID.Ki=0.0f; S_MID.Kd=0.02f;

  // Intro beep
  beep(80); delay(80); beep(80);
}

// ---------- Trajectory generators ----------
float tri_u01(float t, float T){ // triangle 0..1 with period T
  float x = fmodf(t, T) / T;
  return (x<0.5f)? (2*x) : (2*(1-x));
}
float sin_u01(float t, float T){
  return 0.5f*(1.0f - cosf(2.0f*3.1415926535f*(t/T)));
}
float step_u01(float t, float T){
  float x = fmodf(t, T) / T;
  return (x<0.5f)? 0.0f : 1.0f;
}
float u01_by_type(float t, float T){
  if(TRAJ_TYPE==1) return sin_u01(t,T);
  if(TRAJ_TYPE==2) return step_u01(t,T);
  return tri_u01(t,T);
}

// ---------- Control core (per finger) ----------
// struct MotorTargets { int32_t flex_ticks; int32_t ext_ticks; };
MotorTargets compute_targets_idxthumb(const FingerModel& M, FingerState& S, uint8_t id_flex, uint8_t id_ext, int32_t home_flex, int32_t home_ext, int8_t sign_flex, int8_t sign_ext, float Rraw){
  // trajectory
  float u = u01_by_type(S.t_in_phase, S.period); // 0..1
  float theta_tgt = S.theta_lo + (S.theta_hi - S.theta_lo)*u; // deg

  // determine current phase by u slope (triangle/step) or time halves
  Phase ph = (u<0.5f)? PH_FLEX : PH_EXT;
  if(ph != S.phase){ S.phase = ph; S.integ=0; S.prev_err=0; beep(); }

  // feedforward: theta -> L
  const RLPhase& rlp = (ph==PH_FLEX)? M.flex_rl : M.ext_rl;
  const LThetaPhase& ltp = (ph==PH_FLEX)? M.flex_lt : M.ext_lt;
  static float lastL=0;
  float L_ff = 0;
  // invert θ(L) robustly
  {
    // quadratic inversion with trend: use previous L
    float A=ltp.a, B=ltp.b, C=ltp.c - theta_tgt;
    float disc=B*B-4*A*C;
    if(disc>0){
      float sqrtD=sqrtf(disc);
      float L1=(-B+sqrtD)/(2*A);
      float L2=(-B-sqrtD)/(2*A);
      L_ff = (fabsf(L1-lastL) < fabsf(L2-lastL))? L1 : L2;
    }
    lastL = L_ff;
  }
  L_ff = clampL(L_ff, rlp);

  // feedback: sensor -> theta_meas
  float theta_meas = theta_from_R(M, ph, Rraw);
  float err = theta_tgt - theta_meas;

  // PID
  S.integ += err * (LOOP_DT_MS/1000.0f);
  float deriv = (err - S.prev_err) / (LOOP_DT_MS/1000.0f);
  S.prev_err = err;
  float u_corr = S.Kp*err + S.Ki*S.integ + S.Kd*deriv;

  // convert: θ correction -> L correction using local slope dθ/dL ≈ b + 2a L_ff
  float dtheta_dL = ltp.b + 2.0f*ltp.a*L_ff;
  if(fabsf(dtheta_dL) < 1e-3f) dtheta_dL = (dtheta_dL<0)? -1e-3f:1e-3f;
  float L_corr = u_corr / dtheta_dL;

  float L_cmd = clampL(L_ff + L_corr, rlp);

  // convert L to ticks for active motor; inactive holds home
  float rad = (L_cmd / M.spool_r_cm); // since L(cm)=r(cm)*phi(rad)
  int32_t delta_ticks = (int32_t)(rad * TICKS_PER_RAD);
  MotorTargets mt;
  if(ph==PH_FLEX){
    mt.flex_ticks = home_flex + sign_flex * delta_ticks;
    mt.ext_ticks  = home_ext; 
  }else{
    mt.flex_ticks = home_flex;
    mt.ext_ticks  = home_ext + sign_ext * delta_ticks;
  }

  // --- CSV log ---
  static uint32_t t0 = millis();
  uint32_t t = millis() - t0;
  Serial.print("LOG,IDXTH,"); // common for index/thumb
  Serial.print((ph==PH_FLEX)?"FLEX":"EXT"); Serial.print(',');
  Serial.print(t); Serial.print(',');
  Serial.print(theta_tgt,3); Serial.print(',');   // theta_target
  Serial.print(theta_meas,3); Serial.print(',');  // theta_meas
  Serial.print(Rraw,1);        Serial.print(','); // sensor raw
  Serial.print(L_ff,3);        Serial.print(','); // L_ff
  Serial.print(L_cmd,3);       Serial.print(','); // L_cmd
  Serial.print(mt.flex_ticks); Serial.print(',');
  Serial.print(mt.ext_ticks);  Serial.println();
  return mt;
}

MotorTargets compute_targets_middle(const FingerModel& M, FingerState& S, uint8_t id_flex, uint8_t id_ext, int32_t home_flex, int32_t home_ext, int8_t sign_flex, int8_t sign_ext, float Rraw){
  float u = u01_by_type(S.t_in_phase, S.period);
  Phase ph = (u<0.5f)? PH_FLEX : PH_EXT;
  if(ph != S.phase){ S.phase = ph; S.integ=0; S.prev_err=0; beep(); }

  const RLPhase& rlp = (ph==PH_FLEX)? M.flex_rl : M.ext_rl;

  float L_tgt = S.L_lo_cm + (S.L_hi_cm - S.L_lo_cm)*u;  // cm
  L_tgt = clampL(L_tgt, rlp);

  // feedback: sensor -> L_meas
  float L_meas = sensor_to_L(rlp, Rraw);
  float err = L_tgt - L_meas;

  // PID in L-domain
  S.integ += err * (LOOP_DT_MS/1000.0f);
  float deriv = (err - S.prev_err) / (LOOP_DT_MS/1000.0f);
  S.prev_err = err;
  float L_cmd = clampL(L_tgt + (S.Kp*err + S.Ki*S.integ + S.Kd*deriv), rlp);

  float rad = (L_cmd / M.spool_r_cm);
  int32_t delta_ticks = (int32_t)(rad * TICKS_PER_RAD);
  MotorTargets mt;
  if(ph==PH_FLEX){
    mt.flex_ticks = home_flex + sign_flex * delta_ticks;
    mt.ext_ticks  = home_ext;
  }else{
    mt.flex_ticks = home_flex;
    mt.ext_ticks  = home_ext + sign_ext * delta_ticks;
  }

  // CSV log
  static uint32_t t0 = millis();
  uint32_t t = millis() - t0;
  Serial.print("LOG,MID,");
  Serial.print((ph==PH_FLEX)?"FLEX":"EXT"); Serial.print(',');
  Serial.print(t); Serial.print(',');
  Serial.print(L_tgt,3);  Serial.print(',');   // L_target
  Serial.print(L_meas,3); Serial.print(',');   // L_meas
  Serial.print(Rraw,1);   Serial.print(',');   // sensor raw
  Serial.print(mt.flex_ticks); Serial.print(',');
  Serial.print(mt.ext_ticks);  Serial.println();
  return mt;
}

// ---------- Main loop ----------
uint32_t last_ms = 0;

void loop(){
  // serial receive (non-blocking)
  while(Serial.available()){
    char c = Serial.read();
    if(c=='\r') continue;
    if(c=='\n'){
      process_line(sline);
      sline = "";
    }else{
      sline += c;
      if(sline.length()>180) sline="";
    }
  }

  uint32_t now = millis();
  if(now - last_ms < LOOP_DT_MS) return;
  last_ms = now;
  S_IDX.t_in_phase += (LOOP_DT_MS/1000.0f);
  S_THU.t_in_phase += (LOOP_DT_MS/1000.0f);
  S_MID.t_in_phase += (LOOP_DT_MS/1000.0f);

  // read sensors (raw ADC)
  float R_thu = analogRead(PIN_A0);   // A0 thumb
  float R_idx = analogRead(PIN_A1);   // A1 index
  float R_mid = analogRead(PIN_A2);   // A2 middle

  // compute targets
  MotorTargets mt_idx = compute_targets_idxthumb(F_IDX, S_IDX, ID_I_FLEX, ID_I_EXT, HOME_I_FLEX, HOME_I_EXT, SIGN_I_FLEX, SIGN_I_EXT, R_idx);
  MotorTargets mt_thu = compute_targets_idxthumb(F_THU, S_THU, ID_T_FLEX, ID_T_EXT, HOME_T_FLEX, HOME_T_EXT, SIGN_T_FLEX, SIGN_T_EXT, R_thu);
  MotorTargets mt_mid = compute_targets_middle (F_MID, S_MID, ID_M_FLEX, ID_M_EXT, HOME_M_FLEX, HOME_M_EXT, SIGN_M_FLEX, SIGN_M_EXT, R_mid);

  // send to motors
  set_goal_ticks(ID_I_FLEX, mt_idx.flex_ticks);
  set_goal_ticks(ID_I_EXT,  mt_idx.ext_ticks);
  set_goal_ticks(ID_T_FLEX, mt_thu.flex_ticks);
  set_goal_ticks(ID_T_EXT,  mt_thu.ext_ticks);
  set_goal_ticks(ID_M_FLEX, mt_mid.flex_ticks);
  set_goal_ticks(ID_M_EXT,  mt_mid.ext_ticks);
}

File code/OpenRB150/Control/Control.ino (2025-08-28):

/* =========================================================================
 * OpenRB150 Soft Glove — Stable Closed-loop v2 (step-and-hold, 60*66ms)
 *
 * - Two modes: single finger / three-finger synchronous (non-interleaved)
 * - Trajectory rhythm aligned with old code: Flex(60 steps) → Hold → Extend(60 steps) → Hold, repeated NUM_CYCLES times
 * - Buzzer: 1 beep at the start of each segment; 2 beeps before starting; 3 beeps at the very end
 * - Closed-loop: θ_target(t) -> inverse solve L_target -> dL→ticks increment; low-gain PID + rate limiting + deadband + LPF
 * - Direction reversal: configurable sign for each phase depending on wiring
 * - Only torque is enabled for the "current phase" motor, the other side torque is disabled
 * - Logging: CSV (column names compatible with eval_closedloop.py; evaluation works even without θ_gt)
 * =========================================================================*/


#include <Dynamixel2Arduino.h>

/* ---------------- Board & DXL ---------------- */
#define DXL_SERIAL   Serial1
#define DEBUG_SERIAL Serial
#define DXL_DIR_PIN  -1  
#define BUZZER_PIN   10

const float PROTOCOL_VER = 2.0;
const uint32_t USB_BAUD  = 115200;
const uint32_t DXL_BAUD  = 57600;

/* ---------------- Modes ---------------------- */

// #define MODE_SINGLE   1
#define MODE_MULTI    1

// Single finger selection（0=Thumb(A0,1/4), 1=Index(A1,2/5), 2=Middle(A2,3/6)）
const int SINGLE_FINGER = 1;

/* ---------------- Pattern (like old) --------- */
const int   NUM_STEPS   = 60;     // Each section consists of 60 steps
const float STEP_DELAY  = 66;     // Each step 66ms
const int   NUM_CYCLES  = 5;      
const uint16_t HOLD_MS  = 800;    //  break

/* ---------------- Geometry ------------------- */
const float R_CM          = 1.00f;    // Spool radius cm
const float TICKS_PER_REV = 4096.0f;
const float L_PER_REV     = 6.2831853f * R_CM;

/* ---------------- Gains & Limits ------------- */
float Kp = 0.35f, Ki = 0.01f, Kd = 0.0f;

// Maximum tick change allowed every 66ms (soft velocity limit)
const int   MAX_STEP_TICKS   = 40;  
const int   SOFT_TICK_MIN    = -200000;
const int   SOFT_TICK_MAX    =  200000;

// Deadband (if θ error is smaller, ignore to reduce jitter)
const float PHASE_DEADZONE_DEG = 2.0f;

// Low-pass filter (θ measurement, first-order IIR: y+=α(x-y))
const float LPF_ALPHA_THETA = 0.25f;

/* ---------------- Finger map ----------------- */
// Motor IDs：flex(1/2/3), extend(4/5/6)
const uint8_t FLEX_ID[3]   = {1,2,3};
const uint8_t EXTEND_ID[3] = {4,5,6};
// Sensor analog pins
const uint8_t ADC_PIN [3]  = {A0, A1, A2};

int SIGN_FLEX [3] = { -1, -1, -1 };   // Thumb/Index/Middle movement direction in Flex phase
int SIGN_EXT  [3] = { +1, +1, +1 };   // Extend phase

// Target angles (total joint angle). Thumb=∠ABD，Index/Middle=θ_total(=ABC+BCD)
float THETA_FLEX[3] = {45.f, 45.f, 40.f};
float THETA_EXT [3] = { 5.f,  5.f,  5.f};

/* ---------------- Models (R->L, L->θ) --------
 * Note:
 *  - This runtime keeps the “composed model” simplification: measurement uses R->L + L->θ to obtain θ_meas;
 *  - Inverse θ->L uses phase quadratic polynomial 
 *  - Coefficients fill in
 */
struct RLPhase { float lo, hi, qa, qb, qc; };     // L = qa*z^2 + qb*z + qc, z=(R-lo)/(hi-lo)
struct LTPhase { float a, b, c; };                // θ = aL^2 + bL + c

// Thumb
RLPhase RL_T_Flex = { 392.0f, 631.95f,  -0.2769907f, -2.8749299f, -0.1582192f };
RLPhase RL_T_Ext  = { 292.0f, 490.0f,    1.4815102f,  1.8496427f, -3.4713462f };
LTPhase LT_T_Flex = { -3.1875943f, -3.7138699f,  52.790895f };
LTPhase LT_T_Ext  = {  3.8955807f,  9.9750736f,  -0.7871132f };
// Index
RLPhase RL_I_Flex = { 312.0f, 575.19f,   2.6447835f, -6.7967072f, -1.1273738f };
RLPhase RL_I_Ext  = { 263.28f, 409.0f,  -0.2458797f,  3.3552034f, -3.5165549f };
LTPhase LT_I_Flex = { -6.0396793f, -41.807521f, 33.224357f };
LTPhase LT_I_Ext  = { 12.7013474f,  63.726495f, 78.346393f };
// Middle(θ only as proxy)
RLPhase RL_M_Flex = { 440.0f, 779.73f,   2.2007213f, -6.8444605f, -0.8640967f };
RLPhase RL_M_Ext  = { 358.0f, 566.65f,  -0.3096960f,  3.6076787f, -3.5262206f };
LTPhase LT_M_Flex = { 0.f, 1.f, 0.f };
LTPhase LT_M_Ext  = { 0.f, 1.f, 0.f };

// affine (according to active-phase suggested values; not used for Middle)
float AFFINE_A[3] = { 0.9906f, 0.9877f, 1.0f };
float AFFINE_B[3] = { 0.3030f, 0.6574f, 0.0f };

/* ---------------- Runtime -------------------- */
Dynamixel2Arduino dxl(DXL_SERIAL, DXL_DIR_PIN);

enum Phase { Flex=0, Extend=1 };
struct LoopState {
  // State of each finger
  float integ[3]; float prev_err[3]; float theta_lpf[3];
  int   present_tick[3]; int goal_tick[3];
  // Trajectory counters
  int   step_idx; Phase phase;
  unsigned long seg_start_ms;
  int   cycle_idx;
} S;

/* ---------------- Utils ---------------------- */
inline void buzz(int n){
  for(int i=0;i<n;i++){ digitalWrite(BUZZER_PIN, HIGH); delay(100); digitalWrite(BUZZER_PIN, LOW); delay(150); }
}
inline float clampf(float v,float lo,float hi){ return v<lo?lo:(v>hi?hi:v); }
inline int   clampi(int v,int lo,int hi){ return v<lo?lo:(v>hi?hi:v); }

inline float z_from_raw(int raw, const RLPhase& ph){
  float den = (ph.hi>ph.lo)?(ph.hi-ph.lo):1e-6f;
  return (raw - ph.lo)/den;
}
inline float R_to_L_cm(int raw, const RLPhase& ph){
  float z = z_from_raw(raw, ph);
  return ph.qa*z*z + ph.qb*z + ph.qc;
}
inline float L_to_theta(float L, const LTPhase& ph){ return ph.a*L*L + ph.b*L + ph.c; }
inline float dtheta_dL (float L, const LTPhase& ph){ return 2.f*ph.a*L + ph.b; }

//  Quadratic inverse θ->L (choose root close to previous target)
bool invert_theta_to_L(float theta_deg, const LTPhase& ph, float L_hint, float& L_sol){
  float A=ph.a, B=ph.b, C=ph.c - theta_deg;
  if (fabs(A) < 1e-7f){ if (fabs(B)<1e-7f) return false; L_sol = -C/B; return true; }
  float D = B*B - 4*A*C; if (D<0) return false;
  float sD = sqrtf(D);
  float L1 = (-B + sD)/(2*A), L2 = (-B - sD)/(2*A);
  L_sol = (fabs(L1-L_hint)<=fabs(L2-L_hint))?L1:L2;
  return true;
}

void torque_only(uint8_t on_id, uint8_t off_id){
  dxl.torqueOff(off_id);
  dxl.torqueOn(on_id);
}

/* ---------------- Selection helpers ---------- */
inline const RLPhase& RL_of(int f, Phase ph){
  if (f==0) return (ph==Flex)?RL_T_Flex:RL_T_Ext;
  if (f==1) return (ph==Flex)?RL_I_Flex:RL_I_Ext;
  return           (ph==Flex)?RL_M_Flex:RL_M_Ext;
}
inline const LTPhase& LT_of(int f, Phase ph){
  if (f==0) return (ph==Flex)?LT_T_Flex:LT_T_Ext;
  if (f==1) return (ph==Flex)?LT_I_Flex:LT_I_Ext;
  return           (ph==Flex)?LT_M_Flex:LT_M_Ext;
}

/* ---------------- Logging header -------------- */
void print_header(){
  DEBUG_SERIAL.println("Time(ms),Finger,Phase,MotorID,SensorRaw,L_meas_cm,Theta_meas_deg,Theta_target_deg,L_target_cm,GoalTick,PresentTick,Err_theta_deg");
}
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

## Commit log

2025-08-25 Update glove design files
    [index2.SLDPRT, longer2.SLDPRT, middle2.SLDPRT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]
2026-05-16 update result
    [L_theta_direct_summary.csv, R_L_Extend_active.csv, R_L_Flex_active.csv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]
